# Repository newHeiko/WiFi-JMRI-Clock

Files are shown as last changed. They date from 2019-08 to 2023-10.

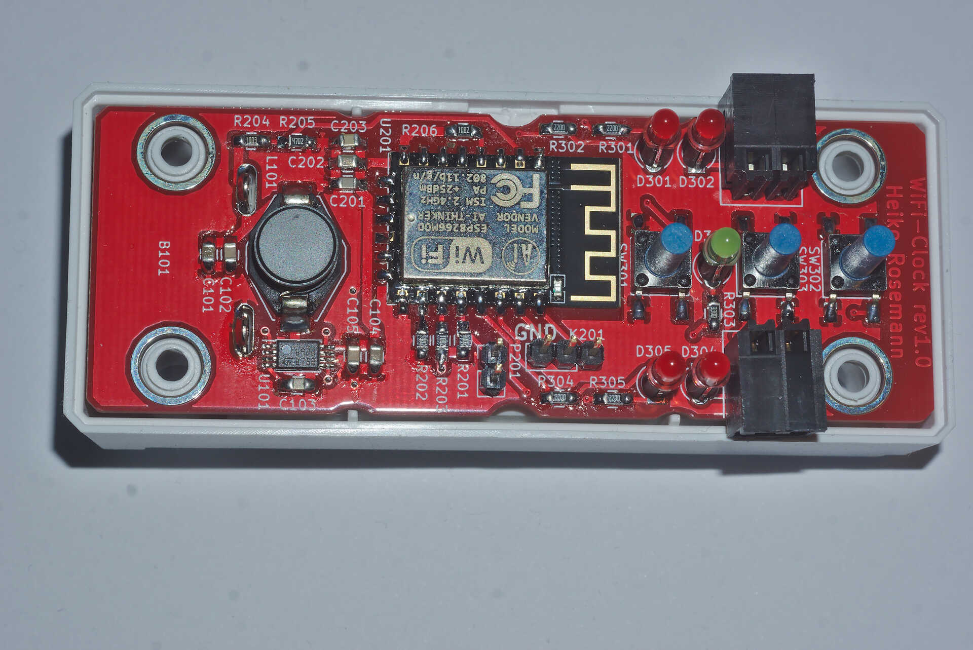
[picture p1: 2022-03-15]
documentation/images/DSC1140.jpg

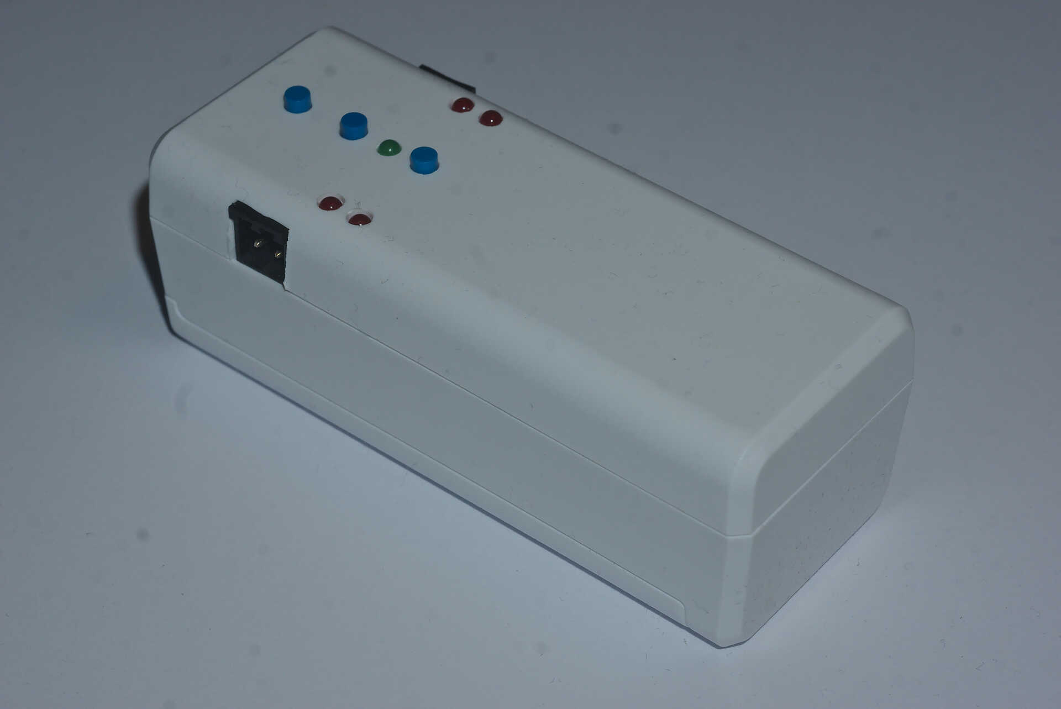
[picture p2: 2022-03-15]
documentation/images/DSC1137.jpg

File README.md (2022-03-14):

# WiFi-JMRI-Clock
Battery-powered WiFi device driving cheap analog wall clocks with clock information from a wiThrottle server.

It is built around ESP12E/ESP12F WiFi modules, powered by 2xAA cells and supposed to fit a Compact AA housing from New Age Enclosures. Configuration will be done through an integrated web server.

This repo contains the schematic and pcb in the hardware/ subfolder and the ESP firmware source code in the form of an Arduino sketch in the software/esp-firmware subfolder.

In-Progress-Version of documentation is available in documentation/ subfolder or at https://newHeiko.github.io/WiFi-JMRI-Clock.

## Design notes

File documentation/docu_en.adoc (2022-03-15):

= WiFi-JMRI-Clock: WiFi device driving cheap analog wall clocks with clock information from a wiThrottle server
Heiko Rosemann
0.1, 3-14-2022: Beginning documentation
:description: Usage documentation, building instructions, schematics, part lists...
:url-repo: https://github.com/newHeiko/WiFi-JMRI-Clock
:icons: image
:iconsdir: images/icons/
:imagesdir: images/
:toc:

WiFi-JMRI-Clock

[abstract]
== Abstract

This document describes the usage and configuration of the WiFi-JMRI-Clock - a device intended for model railroads to fetch the current "model time" from a wiThrottle server and adjust a cheap analog wall clock to the same time and rate. It also contains schematics and BOMs for the device as well as programming instructions and assembly tips.

The most recent version of this document can be found at https://newheiko.github.io/WiFi-JMRI-Clock, https://github.com/newHeiko/WiFi-JMRI-Clock/raw/master/documentation/docu_en.pdf and https://github.com/newHeiko/WiFi-JMRI-Clock/blob/master/documentation/docu_en.adoc.

== Usage

Inserting a pair of AA batteries will start up the WiFi-JMRI-Clock and begin driving the two clock outputs as configured. The device will try to connect to a WiFi network for 60 seconds (if one is enabled in the configuration), then after successful WiFi connect it will connect to a JMRI wiThrottle server on the network. In case no preconfigured WiFi network can be found during those 60 seconds, the device will switch to AP mode and open an access point itself to allow configuration.

[#ledTable]
[cols="1,3"]
.LED status and its meaning for the WiFi-JMRI-Clock
|===
|LED pattern|Status

|Slow blinking (0.5Hz)|Attempting to connect to WiFi network

|Fast blinking (2Hz)|Successful connection to WiFi network, attempting to connect to wiThrottle server and get time

|Steady off|Successful connection to WiFi network and wiThrottle server, at least one time info packet received

|Steady on|Successful connection to WiFi network, configuration mode

|On, flickering off every 2s|No success connecting to WiFi network, setup access point for configuration
|===

[#clockControls]
.Controls and features of the WiFi-JMRI-Clock
Clock interface

The green LED and its blink patterns, as described in <<ledTable>>, will allow some basic diagnosis of this process. The red LEDs are connected directly to the clock outputs, so they will flicker in sync with the pulses output to the clock.

The device will keep a total of three internal clocks running, two to keep track of the clocks connected to the two outputs and one to keep track of network time. The startup time and startup rate of each of the connected clocks can be set individually through the configuration website and the network time will start in sync with the first clock and at the same rate until the first time info packet has been received from the wiThrottle server.

There are three pushbuttons on the WiFi-JMRI-Clock, as shown in <<clockControls>>. The upper two offer a quick way to adjust the time on both connected clocks by a minute or an hour respectively and the third will enable/disable configuration mode when the device is connected to a wiThrottle server.

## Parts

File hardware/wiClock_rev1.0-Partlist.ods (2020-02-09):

Designator | Package | Quantity | Designation | Supplier | ID | Price | Total
U201 | ESP-12E_SMD | 1 | ESP-12E | Elecrow | ESP-12F | 4.760 | 4.76
P1 | PCB | 1 | 88mm x 32mm x 1.6mm | JLCPCB | PCB Service | 0.666666666666667 | 0.67
C203 | C_0805_HandSoldering | 1 | 100u | Mouser | 81-GRM21BR60J107ME5L | 1.595 | 1.59
C101,C102,C104,C105,C202 | C_0805_HandSoldering | 5 | 22u | Mouser | 80-C0805C226M9PACLR | 0.193 | 0.96
B101 | NEW_AGE_COMPACT_AA_PCBEdges | 1 | BATT_HOLDER_2 | Mouser | 789-S1A-361413 | 3.356 | 3.36
B101 | NEW_AGE_COMPACT_AA_PCBEdges | 1 | BATT_HOLDER_2 | Mouser | 789-ACC-AADBL-5212 | 1.028 | 1.03
B101 | NEW_AGE_COMPACT_AA_PCBEdges | 1 | BATT_HOLDER_2 | Mouser | 789-ACC-AAPOS-5223 | 0.386 | 0.39
B101 | NEW_AGE_COMPACT_AA_PCBEdges | 1 | BATT_HOLDER_2 | Mouser | 789-ACC-AANEG-5201 | 0.488 | 0.49
D301,D302,D303,D304,D305 | LED Spacer | 5 | 7mm | Mouser | 749-ELM-7-7MM | 0.045 | 0.23
SW303,SW302,SW301 | Taster_9319 | 3 | SW_PUSH | Mouser | 611-PTS645SM13SMTR92 | 0.311 | 0.93
R301,R302,R304,R305 | C_0805_HandSoldering | 4 | 220 | Reichelt | SMD-0805 220 | 0.015 | 0.06
R303 | C_0805_HandSoldering | 1 | 330 | Reichelt | SMD-0805 330 | 0.015 | 0.02
R204 | C_0805_HandSoldering | 1 | 100k | Reichelt | SMD-0805 100,0K | 0.015 | 0.02
C103,C201 | C_0805_HandSoldering | 2 | 100n | Reichelt | KEM X7R0805 100N | 0.040 | 0.08
R201,R202,R203,R206 | C_0805_HandSoldering | 4 | 10k | Reichelt | SMD-0805 10,0K | 0.015 | 0.06
L101 | L_Fastron_PISN_Handsoldering | 1 | 22u | Reichelt | L-PISM 22µ | 0.760 | 0.76
R205 | C_0805_HandSoldering | 1 | 47k | Reichelt | SMD-0805 47,0K | 0.015 | 0.02
P301 | AKL183-02 | 1 | CLOCK1 | Reichelt | AKL 183-02 | 0.260 | 0.26
P301 | AKL169-02 | 1 | CLOCK1 | Reichelt | AKL 169-02 | 0.530 | 0.53
P302 | AKL183-02 | 1 | CLOCK2 | Reichelt | AKL 183-02 | 0.260 | 0.26
P302 | AKL169-02 | 1 | CLOCK2 | Reichelt | AKL 169-02 | 0.530 | 0.53
P201 | Pin_Header_Straight_1x02_Pitch2.54mm | 1 | ESP_BOOTLOAD | Reichelt | SL 1X40G 2,54 (1/20) | 0.010 | 0.01
D303 | LED_D3.0mm | 1 | green | Reichelt | LED 3MM GN | 0.070 | 0.07
U101 | TSSOP-8_4.4x3mm_Pitch0.65mm | 1 | L6920D | Reichelt | L 6920 D | 1.650 | 1.65
D301,D302,D304,D305 | LED_D3.0mm | 4 | red | Reichelt | LED 3MM RT | 0.070 | 0.28
K201 | Pin_Header_Straight_1x03_Pitch2.54mm | 1 | UART_ESP | Reichelt | SL 1X40G 2,54 (1/10) | 0.020 | 0.02
Summe |  |  |  |  |  |  | 19.04

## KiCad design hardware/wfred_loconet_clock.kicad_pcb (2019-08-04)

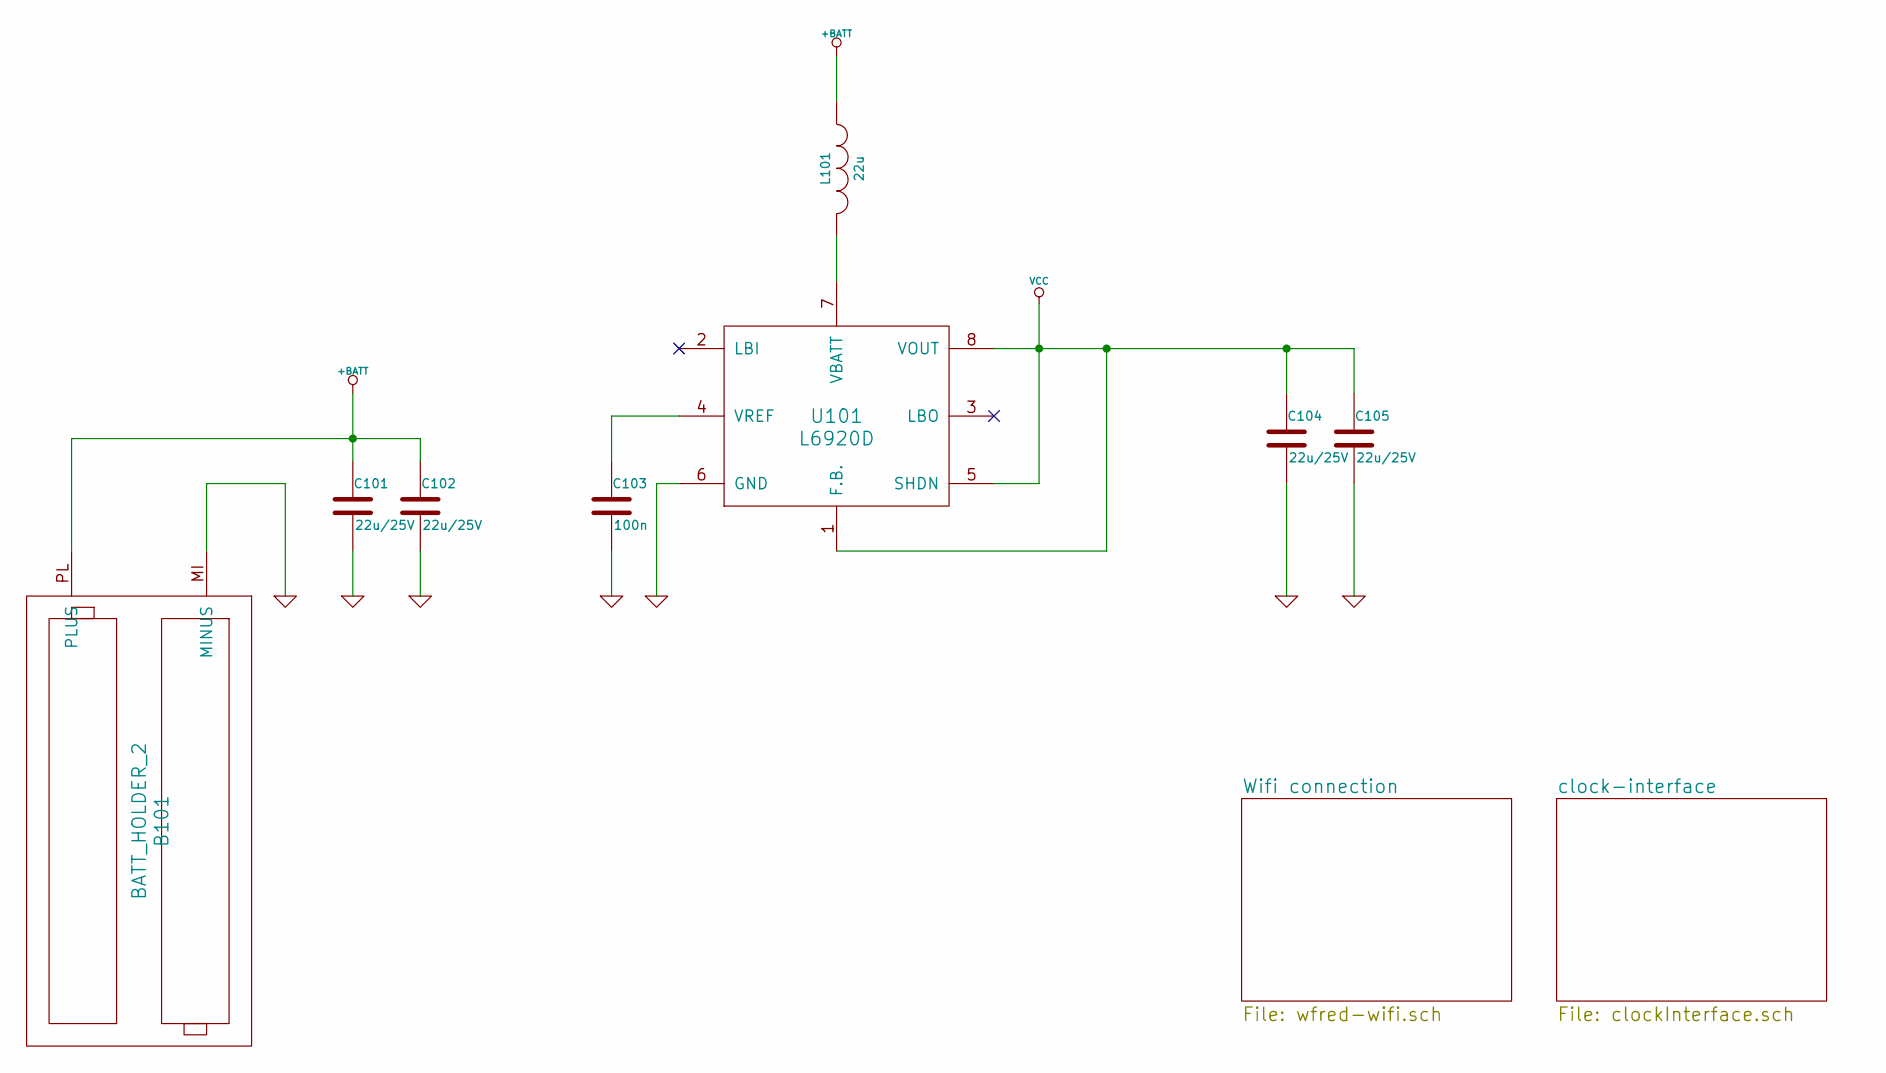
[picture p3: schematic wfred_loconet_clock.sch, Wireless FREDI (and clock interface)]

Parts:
B101: BATT_HOLDER_2; NEW_AGE_COMPACT_AA_PCBEdges
C101, C102, C104, C105: 22u/25V; C_0805_HandSoldering
C103: 100n; C_0805_HandSoldering
L101: 22u; L_Fastron_PISN_Handsoldering
U101: L6920D; TSSOP-8_4.4x3mm_Pitch0.65mm; Mouser 511-L6920DTR

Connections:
+BATT: B101.PL (PLUS), C101.1, C102.1, L101.1; also elsewhere on the board
GND: B101.MI (MINUS), C101.2, C102.2, C103.2, C104.2, C105.2, U101.6 (GND); also elsewhere on the board
unnamed: C103.1, U101.4 (VREF)
unnamed: L101.2, U101.7 (VBATT)
VCC: C104.1, C105.1, U101.1 (F.B.), U101.5 (SHDN), U101.8 (VOUT); also elsewhere on the board

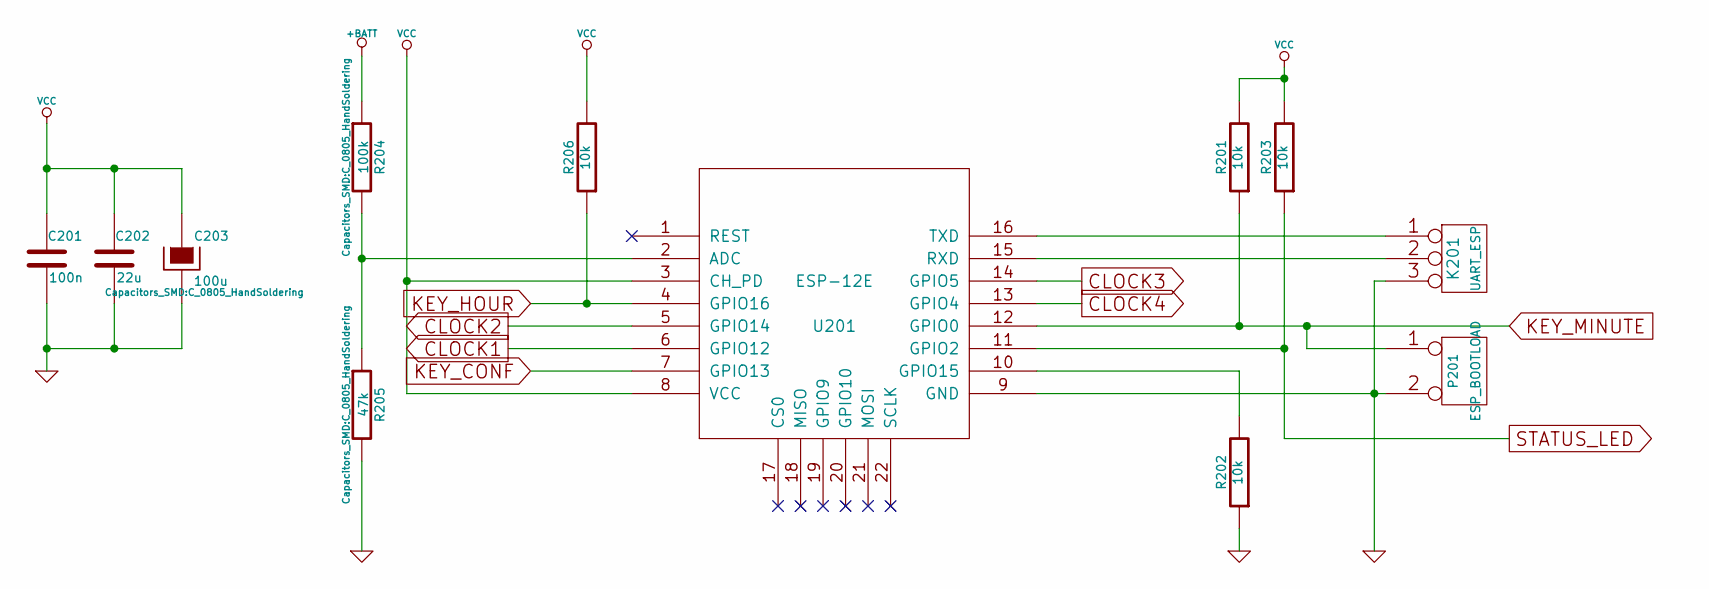
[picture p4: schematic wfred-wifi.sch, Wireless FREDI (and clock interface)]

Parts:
C201: 100n; C_0805_HandSoldering
C202: 22u; C_0805_HandSoldering
C203: 100u; C_0805_HandSoldering
K201: UART_ESP; Pin_Header_Straight_1x03_Pitch2.54mm
P201: ESP_BOOTLOAD; Pin_Header_Straight_1x02_Pitch2.54mm
R201, R202, R203, R206: 10k; C_0805_HandSoldering; Mouser 603-RC0805JR-0710KL
R204: 100k; C_0805_HandSoldering
R205: 47k; C_0805_HandSoldering
U201: ESP-12E; ESP-12E_SMD

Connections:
+BATT: R204.1; also elsewhere on the board
CLOCK1: U201.6 (GPIO12); also elsewhere on the board
CLOCK2: U201.5 (GPIO14); also elsewhere on the board
CLOCK3: U201.14 (GPIO5); also elsewhere on the board
CLOCK4: U201.13 (GPIO4); also elsewhere on the board
GND: C201.2, C202.2, C203.2, K201.3, P201.2 (PM), R202.1, R205.2, U201.9 (GND); also elsewhere on the board
KEY_CONF: U201.7 (GPIO13); also elsewhere on the board
KEY_HOUR: R206.1, U201.4 (GPIO16); also elsewhere on the board
KEY_MINUTE: P201.1, R201.1, U201.12 (GPIO0); also elsewhere on the board
unnamed: K201.1, U201.16 (TXD)
unnamed: K201.2 (PM), U201.15 (RXD)
unnamed: R202.2, U201.10 (GPIO15)
unnamed: R204.2, R205.1, U201.2 (ADC)
STATUS_LED: R203.1, U201.11 (GPIO2); also elsewhere on the board
VCC: C201.1, C202.1, C203.1, R201.2, R203.2, R206.2, U201.3 (CH_PD), U201.8 (VCC); also elsewhere on the board

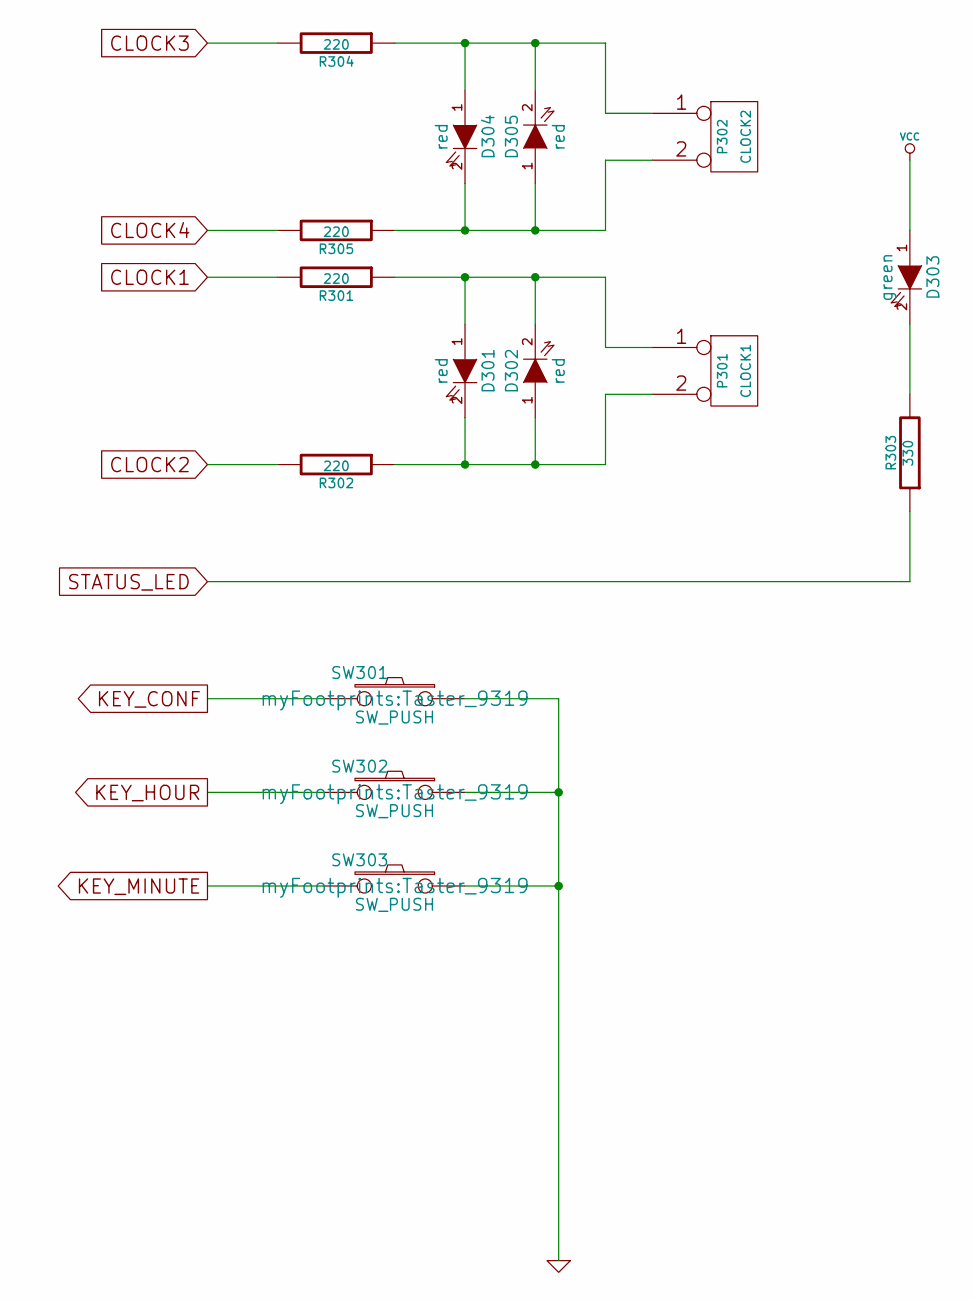
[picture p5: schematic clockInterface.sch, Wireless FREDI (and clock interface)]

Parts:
D301, D302, D304, D305: red; LED_D3.0mm
D303: green; LED_D3.0mm
P301: CLOCK1; AKL183-02
P302: CLOCK2; AKL183-02
R301, R302, R304, R305: 220; C_0805_HandSoldering; Mouser 603-RC0805JR-07220RL
R303: 330; C_0805_HandSoldering; Mouser 603-RC0805JR-07220RL
SW301, SW302, SW303: SW_PUSH; Taster_9319; Mouser 611-PTS645SM13SMTR92

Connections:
CLOCK1: R301.2; also elsewhere on the board
CLOCK2: R302.2; also elsewhere on the board
CLOCK3: R304.2; also elsewhere on the board
CLOCK4: R305.2; also elsewhere on the board
GND: SW301.1, SW302.1, SW303.1; also elsewhere on the board
KEY_CONF: SW301.2; also elsewhere on the board
KEY_HOUR: SW302.2; also elsewhere on the board
KEY_MINUTE: SW303.2; also elsewhere on the board
unnamed: D301.1 (A), D302.2 (K), P301.1, R301.1
unnamed: D301.2 (K), D302.1 (A), P301.2 (PM), R302.1
unnamed: D303.2 (K), R303.2
unnamed: D304.1 (A), D305.2 (K), P302.1, R304.1
unnamed: D304.2 (K), D305.1 (A), P302.2 (PM), R305.1
STATUS_LED: R303.1; also elsewhere on the board
VCC: D303.1 (A); also elsewhere on the board

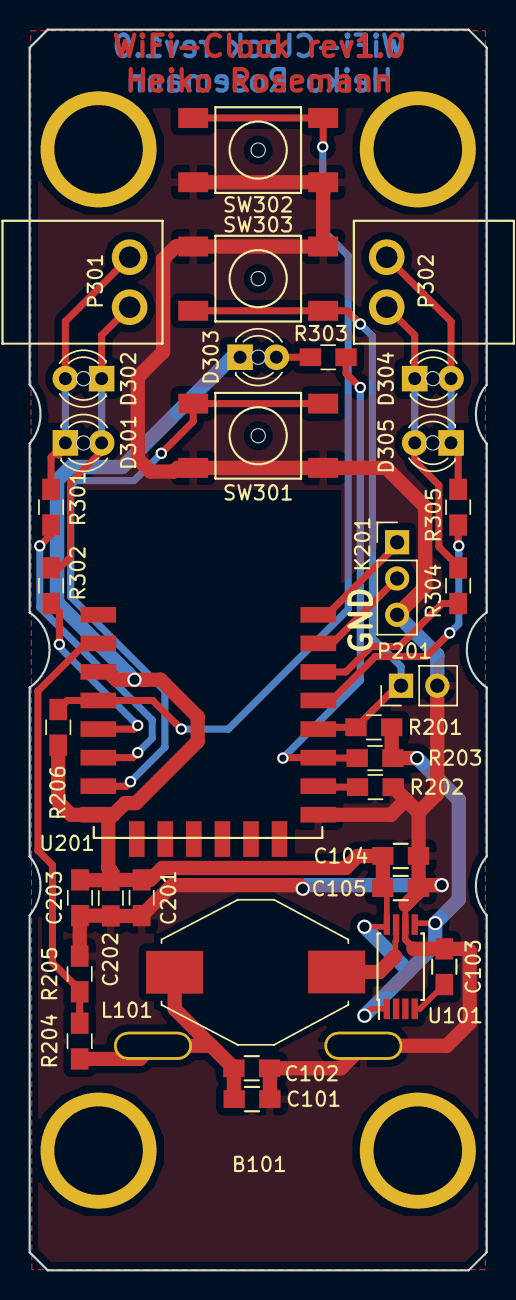
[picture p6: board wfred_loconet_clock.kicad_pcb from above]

Board: 2 copper layers, 32.0 x 86.9 mm, 35 parts (0 on the bottom side), 22 nets.

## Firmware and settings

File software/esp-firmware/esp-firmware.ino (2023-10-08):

/**
 * This file is part of the wiClock wireless model railroading fastclock project
 * Copyright (C) 2018-2023 Heiko Rosemann
 *
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
 * This file ties everything together to initialize the hardware and
 * form the main loop.
 * 
 * This project was made for ESP12E/ESP12F with Arduino ESP version 2.5.2
 * Board settings: Generic ESP8266 Module, 80MHz, Flash, Disabled, ck, 26MHz,
 * 40MHz, DOUT (compatible), 4M (1M SPIFFS), 2, v1.4 Higher Bandwidth, 
 * Disabled, None, Only Sketch, 115200 on /dev/ttyUSB0
 */
/* Boards:
 * - Generic ESP8266 Module * esp8266:esp8266:generic:led=2,baud=115200,xtal=80,CrystalFreq=26,eesz=4M1M,FlashMode=dout,FlashFreq=40,ResetMethod=nodtr_nosync,dbg=Disabled,lvl=None____,ip=hb2f,vt=flash,exception=disabled,stacksmash=disabled,wipe=none,sdk=nonosdk_191122,ssl=basic,mmu=3232,non32xfer=fast,CONSOLEBAUD=115200
 */

#include "wifi.h"
#include "config.h"
#include "lowbat.h"
#include "stateMachine.h"
#include "ui.h"

// #define DEBUG

state wiFredState = STATE_STARTUP;
uint32_t stateTimeout = UINT32_MAX;

void setup() {
// put your setup code here, to run once:

  initUI();
  Serial.begin(115200);
  Serial.setTimeout(10);
  initConfig();
  initClock();
  
  #ifdef DEBUG
  Serial.setDebugOutput(true);
  #else
  Serial.setDebugOutput(false);
  #endif
  delay(100);

  initWiFi();
}

void loop() {
  // put your main code here, to run repeatedly:
  handleWiFi();
  handleNewTime();
  lowBatteryHandler();

#ifdef DEBUG
  static uint32_t test = 0;

  if(test < millis())
  {
    test = millis() + 5000;
    Serial.println(ESP.getFreeHeap());
  }
#endif

  if(emptyBattery)
  {
    WiFi.disconnect();
    WiFi.mode(WIFI_OFF);
    ESP.deepSleep(0);
  }
  
  switch(wiFredState)
  {
    case STATE_STARTUP:
      setLED(100, 200);
      switchState(STATE_CONNECTING, 60 * 1000);
      initWiFiSTA();
      break;
      
    case STATE_CONNECTING:
      setLED(100, 200);
      if(WiFi.status() == WL_CONNECTED)
      {
        setLED(25, 50);
        initMDNS();
        switchState(STATE_CONNECTED, 60 * 1000);
      }
      else if(millis() > stateTimeout)
      {
        setLED(190, 200);
        initWiFiAP();
        switchState(STATE_CONFIG_AP);
      }
      break;

    case STATE_CONNECTED:
    case STATE_SERVERCONN:
    case STATE_ONLINE:
      if(getInputPressed(KEY_CONFIG) == true)
      {
        setLED(100, 100);
        initWiFiConfigSTA();
        switchState(STATE_CONFIG_STATION_WAITING, 120 * 1000);
        break;
      }      

      if(WiFi.status() != WL_CONNECTED)
      {
        switchState(STATE_STARTUP);
        break;
      }
      switch(wiFredState)
      {
        case STATE_CONNECTED:
          clockConnect();
          break;
        case STATE_SERVERCONN:
          clockServerRegister();
          break;
        case STATE_ONLINE:
          clockHandler();
          break;
        default:
          break;
      }
      break;

    case STATE_CONFIG_STATION_WAITING:
      setLED(100, 100);
      if(millis() > stateTimeout || getInputPressed(KEY_CONFIG) == true)
      {
        setLED(25, 50);
        shutdownWiFiConfigSTA();
        switchState(STATE_CONNECTED);
      }
      break;

    case STATE_CONFIG_STATION:
      if(getInputPressed(KEY_CONFIG) == true)
      {
        setLED(25, 50);
        shutdownWiFiConfigSTA();
        switchState(STATE_CONNECTED);
      }

      if(WiFi.status() != WL_CONNECTED)
      {
        switchState(STATE_STARTUP);
      }

      break;

    case STATE_CONFIG_AP:
    // no way to get out of here except for restart
      setLED(190, 200);
      break;
  }
}

void switchState(state newState, uint32_t timeout)
{
  wiFredState = newState;
  if(timeout == UINT32_MAX)
  {
    stateTimeout = timeout;
  }
  else
  {
    stateTimeout = millis() + timeout;
  }
}

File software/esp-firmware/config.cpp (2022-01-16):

/**
 * This file is part of the wiClock wireless model railroading fastclock project
 * Copyright (C) 2018-2021 Heiko Rosemann
 *
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
 * This file provides functions for handling configuration settings in
 * non-volatile memory.
 */

/*
 * The SPIFFS code is deprecated, so this file will throw a lot of warnings
 * which I'm happy to ignore for now.
 * 
 * Possibly the project will transition to LittleFS once it's included 
 * in the standard arduino boards package.
 */
#pragma GCC diagnostic ignored "-Wdeprecated-declarations"

#include <stdbool.h>
#include <FS.h>
#include <ArduinoJson.h>

#include "config.h"
#include "wifi.h"
#include "clockHandling.h"

char * throttleName;

/*
 * Read all configuration from EEPROM
 */
void initConfig(void)
{
  uint8_t mac[6];
  WiFi.macAddress(mac);
  String tN = "wiClock-" + String(mac[0], 16) + String(mac[5], 16);
  throttleName = strdup(tN.c_str());

  clockServer.automatic = true;
  clockServer.name = strdup("undef");
  clockServer.port = 12090;

  for(uint8_t i=0; i<NUM_CLOCKS; i++)
  {
    startupTime[i].hours = 5;
    startupTime[i].minutes = 30;
    startupTime[i].seconds = 0;
    startupTime[i].rate10 = 10;
    
    clockHW[i].clockMaxTickFrequency = 6;
    clockHW[i].clockPulseLength = 40;
    clockHW[i].clockMode = CLOCK_MODE_SECOND;
  }
  
  if(!SPIFFS.begin())
  {
    return;
  }
  
  DynamicJsonDocument doc(256);

// read device name from SPIFFS
  if(File f = SPIFFS.open(FN_NAME, "r"))
  {
    if(!deserializeJson(doc, f))
    {
      const char * s = doc[FIELD_NAME_NAME];
      if(s != nullptr)
      {
        free(throttleName);
        throttleName = strdup(s);
      }
    }
    f.close();
  }

// read server configuration/information from SPIFFS
  if(File f = SPIFFS.open(FN_SERVER, "r"))
  {
    if(!deserializeJson(doc, f))
    {
      const char * s = doc[FIELD_SERVER_NAME];
      if(s != nullptr)
      {
        free(clockServer.name);
        clockServer.name = strdup(s);
      }
      uint16_t p = doc[FIELD_SERVER_PORT];
      if(p != 0)
      {
        clockServer.port = p;
      }
      if(doc.containsKey(FIELD_SERVER_AUTOMATIC))
      {
        clockServer.automatic = doc[FIELD_SERVER_AUTOMATIC];
      }
    }
    f.close();
  }

// read startup time from SPIFFS - global settings from old system
  if(File f = SPIFFS.open(FN_STARTUP_TIME, "r"))
  {
    if(!deserializeJson(doc, f))
    {
      if( doc.containsKey(FIELD_STARTUP_HOUR) && doc.containsKey(FIELD_STARTUP_MINUTE) 
       && doc.containsKey(FIELD_STARTUP_SECOND) && doc.containsKey(FIELD_STARTUP_RATE) )
      {
        for(uint8_t i = 0; i<NUM_CLOCKS; i++)
        {
          startupTime[i].hours = doc[FIELD_STARTUP_HOUR];
          startupTime[i].minutes = doc[FIELD_STARTUP_MINUTE];
          startupTime[i].seconds = doc[FIELD_STARTUP_SECOND];
          startupTime[i].rate10 = doc[FIELD_STARTUP_RATE];
        }
      }
    }
    f.close();
  }

// read startup time from SPIFFS - per-clock settings from new system
  for(uint8_t i = 0; i<NUM_CLOCKS; i++)
  {
    String filename = String(i) + FN_STARTUP_TIME;
    if(File f = SPIFFS.open(filename, "r"))
    {
      if(!deserializeJson(doc, f))
      {
        if( doc.containsKey(FIELD_STARTUP_HOUR) && doc.containsKey(FIELD_STARTUP_MINUTE) 
         && doc.containsKey(FIELD_STARTUP_SECOND) && doc.containsKey(FIELD_STARTUP_RATE) )
        {
          startupTime[i].hours = doc[FIELD_STARTUP_HOUR];
          startupTime[i].minutes = doc[FIELD_STARTUP_MINUTE];
          startupTime[i].seconds = doc[FIELD_STARTUP_SECOND];
          startupTime[i].rate10 = doc[FIELD_STARTUP_RATE];
        }
      }
      f.close();
    }
  }

// read clock configuration from SPIFFS - global settings from old system
  if(File f = SPIFFS.open(FN_CLOCK_CONFIG, "r"))
  {
    if(!deserializeJson(doc, f))
    {
      for(uint8_t i = 0; i<NUM_CLOCKS; i++)
      {
        if(doc.containsKey(FIELD_CLOCK_MAXRATE))
        {
          clockHW[i].clockMaxTickFrequency = doc[FIELD_CLOCK_MAXRATE];
        }
        if(doc.containsKey(FIELD_CLOCK_PULSELENGTH))
        {
          clockHW[i].clockPulseLength = doc[FIELD_CLOCK_PULSELENGTH];
        }
        if(doc.containsKey(FIELD_CLOCK_MINUTEMODE))
        {
          if(doc[FIELD_CLOCK_MINUTEMODE])
          {
            clockHW[i].clockMode = CLOCK_MODE_MINUTE;
          }
        }
        if(doc.containsKey(FIELD_CLOCK_MODE))
        {
          clockHW[i].clockMode = doc[FIELD_CLOCK_MODE];
        }
      }
    }
    f.close();
  }
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

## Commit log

2019-02-12 Removed wiFred info from from clock project
    [User_interface_rev2.sch, clockInterface.sch, loconet-interface.sch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]
2019-02-12 Untangle throttle functions from WiFi-JMRI-Clock
2019-02-13 Fix schematic after untangling from wiFred
    [clockInterface.sch, wfred-wifi.sch, wfred_loconet_clock.sch]
2019-02-13 Fixed PCB after untangling
    [wfred_loconet_clock.kicad_pcb]
2019-03-07 Change project info in source files
    - project description from throttle to clock
    - project build info
2019-03-07 Add new input button and led handling code
    ...and replace calls to removed code with calls to new code, as well as
    add calls to LED settings
    [clockHandling.cpp, ui.cpp]
2019-03-07 Re-work battery status management
    - Re-add old battery voltage measurement code
    - Handle empty battery status unconditionally in main loop, getting rid
    of LOW_POWER* states
2019-03-08 Change clock schematic and PCB
    - Remove slide switches, replace with single push button
    - Add status LED
    - Re-add battery measurement connection
    - Change PCB form factor to fit NewAgeEnclosures Compact AA housing
    - Re-layout PCB
    [clockInterface.sch, wfred-wifi.sch, wfred_loconet_clock.kicad_pcb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]
2019-03-10 Changed PCB and code to closer match first PCB
    - Add battery measurement resistors
    - Move key, status LED and clock I/O-pins around to match first PCB
    (except for CLOCK1 which is on low power pin in first version)
    [clockInterface.sch, wfred-wifi.sch, wfred_loconet_clock.kicad_pcb]
2019-03-11 Correct clock, led and input switch pin associations
    [clockHandling.h]
2019-03-11 Change wording from wiFred to wiClock...
    ...and also switch Arduino.h for ESP8266WiFi.h include and change LED
    blink code for CONFIG_AP
2019-04-07 Added more keys to the PCB for adjusting the time
    [clockInterface.sch, wfred-wifi.sch, wfred_loconet_clock.kicad_pcb]
2019-04-20 Changes to kicad files due to library update/rescue
2019-04-21 Revert "Add catch-all-DNS-server to config-AP-mode"
    This reverts commit fd152f8f4f9196d7bcbb3e4bec8e7f7e90fd10e0.
    [wifi.cpp]
2019-05-12 Derive default device name from MAC address
2019-05-12 Add DNS server and mDNS responder
    - catchall DNS server for "captive mode" when device is running as softAP
    - mDNS responder when connected to WiFi in "normal mode" will broadcast
    http service as <throttleName>.local (sanitized, only alpha-numeric
    characters allowed)
    - mDNS responder when connected to WiFi in "config mode" will broadcast
    http service config.local
    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
2019-05-12 Adapt to debugging on NodeMCU
    - set DEBUG defines
    - disable shutdown on low battery
    - change pin and LED settings to match NodeMCU hardware
2019-05-12 Revert "Adapt to debugging on NodeMCU"
    This reverts commit 105eb5fb26e527b0c10b249fa7aa00d5727972b6.
    [wifi.cpp]
2019-07-01 Carry over missing .html bugfix from wiFred
    [wifi.cpp]
2019-08-02 Add second clock output...
    ...while removing (so far) unused key
    [clockInterface.sch, wfred-wifi.sch, wfred_loconet_clock.kicad_pcb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]
2019-08-04 Fixed missing GND connection on PCB...
    ...found during order process.
    [wfred_loconet_clock.kicad_pcb]
2019-08-27 Add a BOM file for wiClock 1.0
    [wiClock_rev1.0-Partlist.ods]
2019-11-08 Update Partlist to currently available parts
    [wiClock_rev1.0-Partlist.ods]
2019-11-08 Begin rework to support v1.0-version
    - Add second clock info structure
    - Handle three keys instead of four
    - Add defines for second clock output
    [clockHandling.cpp, clockHandling.h, ui.cpp]
2019-11-10 WIP: Handle more than one clock
    - Added clockInfo fields
    - Removed global variables
    - Changed ticker callbacks to accept arguments
    TBD: Correct newTime handling in clockHandler()
    TBD: Add second clock to web server page
    [clockHandling.cpp, clockHandling.h, wifi.cpp]
2019-11-12 Add handling of hour and minute input switches
    BUG: Ignores hour switch
    [clockHandling.cpp]
2019-11-12 Bugfix: Include KEY_HOUR in key handling
    [ui.cpp]
2019-11-12 Bugfix: Roll-under from 00:xx:xx to 11:xx:xx
    ...instead of %= 12 leading to 03:xx:xx
    [clockHandling.cpp]
2019-11-13 Add current firmware revision info...
    ...from git
2019-12-30 Corrected AKL 183-02 / AKL 169-02 to include both
    ...numbers in BOM.
    [wiClock_rev1.0-Partlist.ods]
2020-02-09 Updated part list
    [wiClock_rev1.0-Partlist.ods]
2020-02-09 Opened schematic and pcb with kicad 5.1.5...
    ...to update library table
    [clockInterface.sch, wfred-wifi.sch, wfred_loconet_clock.sch]
2020-04-20 Added second clock and switched to minute mode
    Also consolidated configuration and changed catch-up behaviour to slow
    down when closing in on correct time.
    [clockHandling.cpp, clockHandling.h, config.cpp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]
2021-12-26 Fix a bunch of warnings
    - Warnings about wrong char[] length calculation -> switch char[] to String
    - Suppress deprecated warnings for SPIFFS
    [config.cpp]
2021-12-26 Fix string length warnings
    - just increase buffer size, even though hours/minutes/seconds are all
    limited to two digits, can't find out how to tell GCC that
    [wifi.cpp]
2021-12-27 Remove clock offset from UTC
    ...in preparation to switching to wiThrottle server as clock source.
2021-12-27 Switch port and MDNS service to withrottle server
2022-01-09 Switched over to constant wiThrottle connection
    - Added state transitions
2022-01-16 Switched from bool minuteMode to enum clockMode
    ...to support more modes for sweeping clocks.
    So far, only minute mode and second mode work right.
2022-03-14 Switch file names to English
2022-03-15 Documentation update: Usage, LED, pushbuttons
2023-10-08 Add board configuration for IniIno into sketch
    Get it here: https://github.com/tykefcz/IniIno

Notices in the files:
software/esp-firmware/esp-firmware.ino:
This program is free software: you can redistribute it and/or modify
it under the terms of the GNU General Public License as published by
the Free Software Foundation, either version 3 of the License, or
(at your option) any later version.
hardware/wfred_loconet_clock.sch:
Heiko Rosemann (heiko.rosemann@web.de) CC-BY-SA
